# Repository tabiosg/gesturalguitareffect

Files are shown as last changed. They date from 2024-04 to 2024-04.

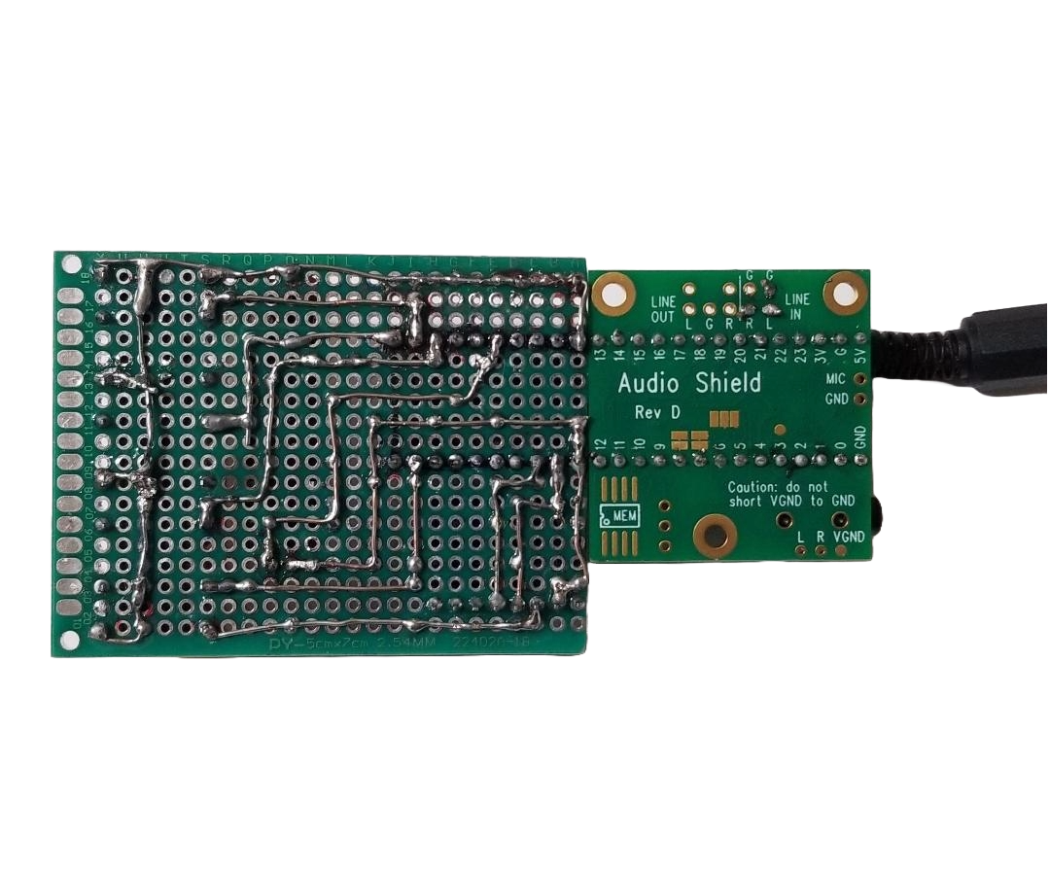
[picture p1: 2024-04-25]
design/protoboard_back.png

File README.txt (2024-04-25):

Gesturally Controlled Guitar Sound Effects Board

This project developed a real-time signal-processing sound effects board tailored for musicians' live performances, utilizing microcontrollers to manipulate input signals for specific outputs.
The current implementation allows for tremolo, wah, and delay effects.

This project was made during the W24 semester for EECS 452.

Zip Content:

design/ contains all designs implemented in project.
    This is primarily focused on the 3D-housing info but also the soldered protoboard.
src/ has the source code.
    src/data_collection has the code which was used to collect data during milestone 1
        This was achieved by dumping debug information over serial and having a Python script
        snoop the line.
    fw/final/gesturalguitareffect has the final firmware code to be flashed on the Teensy.
    sim/ has the code to run the simulation, which is independent of real hardware.
2024-Team-1-final.pdf has the final project report.
2024-Team-1-poster.pdf has the poster used during the demo and expo.
COPYRIGHT.txt contains copyright information, and allows usage of project for educational purposes

Contact Information: 
Eric Cooley - ecooley@umich.edu
Guthrie Tabios - tabiosg@umich.edu
Hypatia Magyar - hypatiam@umich.edu
Leah Kim - leahckim@umich.edu
Nicholas West - nicwest@umich.edu

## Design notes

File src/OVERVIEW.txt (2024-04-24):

All of the code in data_collection/ was only used during milestone 1 to get more data. This is optional.
It worked by taking in the serial debug statements printed by the Teensy and plotting that data afterward.
This serial debug feature will not work perfectly with all the newest code changes to the firmware.

All of the code in src/final/gesturalguitareffect is what is needed to be flashed on the Arduino.
The accelerometer.h and potentiometer.h files are self-explanatory.
The guitareffects.h describes all of our possible effects in an enum.
delay.audiogestural.cpp, tremolo.audiogestural.cpp, and wah.audiogestural.cpp have the specific guitar effect implementations.
audiogestural.cpp and audiogestural.h list the generic functions for the custom AudioStream class.
gesturalguitareffect.ino has the main logic for collecting data in the loop(), used to update parameters.

Al of the code in sim/ is what is needed to run the sim.

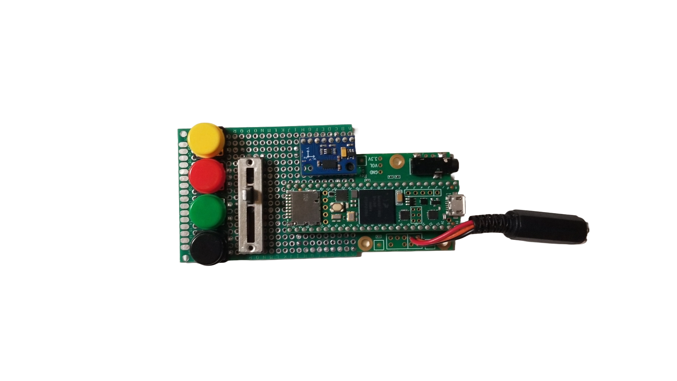
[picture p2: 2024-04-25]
design/protoboard_front.png

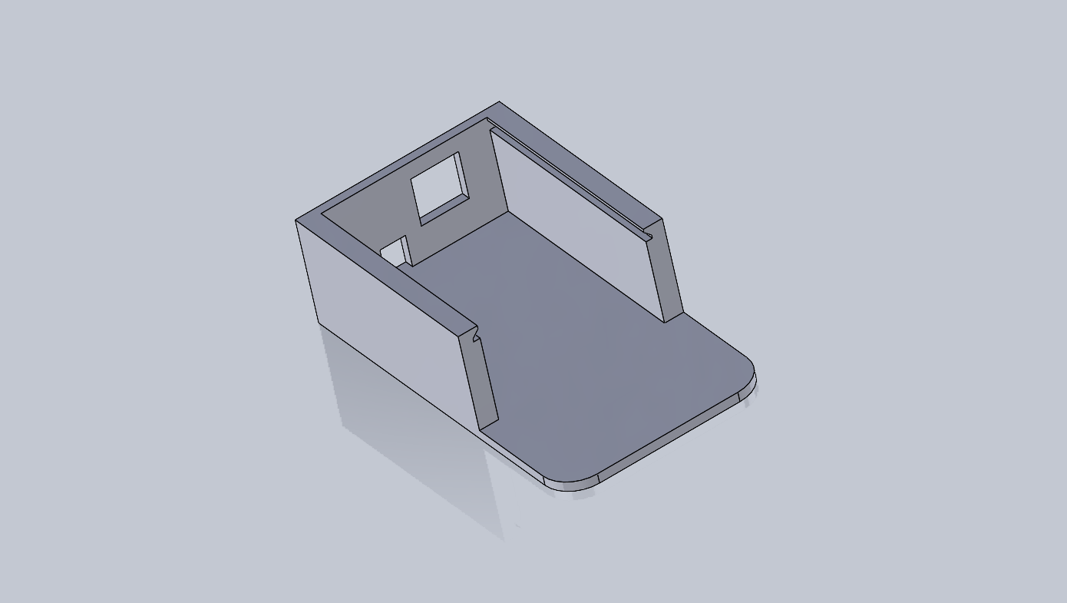
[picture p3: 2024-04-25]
design/box.PNG

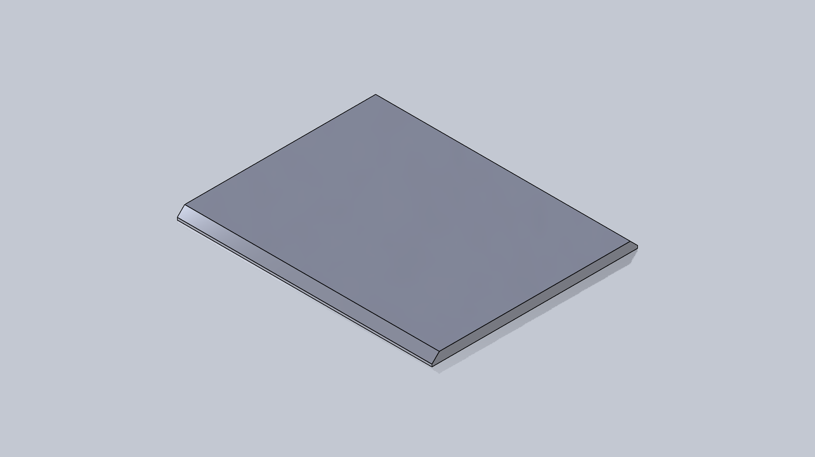
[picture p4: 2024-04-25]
design/lid.PNG

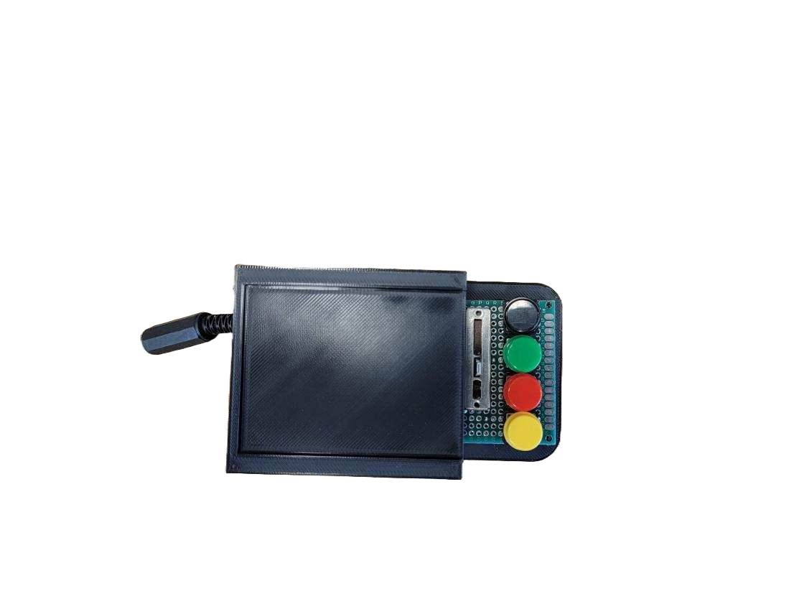
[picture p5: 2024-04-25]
design/final_unit.png

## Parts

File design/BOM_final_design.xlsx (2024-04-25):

Description | Link | Qty | Price
Teensy Audio Shield | From lab | 1 | $16 | Price estimated
Teensy 4.1 | From lab | 1 | $35 | Price estimated
Accelerometer | https://shop.pimoroni.com/en-us/products/lsm303d-6dof-motion-sensor-breakout | 1 | $9.99
Tactile Push Buttons | https://www.amazon.com/Gikfun-12x12x7-3-Tactile-Momentary-Arduino/dp/B01E38OS7K?sp_csd=d2lkZ2V0TmFtZT1zcF9hdGY | 1 | $8.68
Slide Potentiometer | https://www.digikey.com/en/products/detail/bourns-inc/PTA2043-2015CPB103/3781176 | 1 | $1.71
Velcro | https://www.amazon.com/VELCRO-Brand-Fasteners-Industrial-VEL-30703-USA/dp/B09BNPX3XJ | 1 | $8.90
Instrument Cable | Already owned | 1 | $10 | Price estimated
Aux to Instrument Cable Adapter | https://www.amazon.com/TISINO-Female-Headphone-Adapter-Amplifiers/dp/B08KW24ZV9 | 1 | $8.99
Aux Cable | Already owned | 1 | $5 | Price estimted
Total |  |  | $104.27

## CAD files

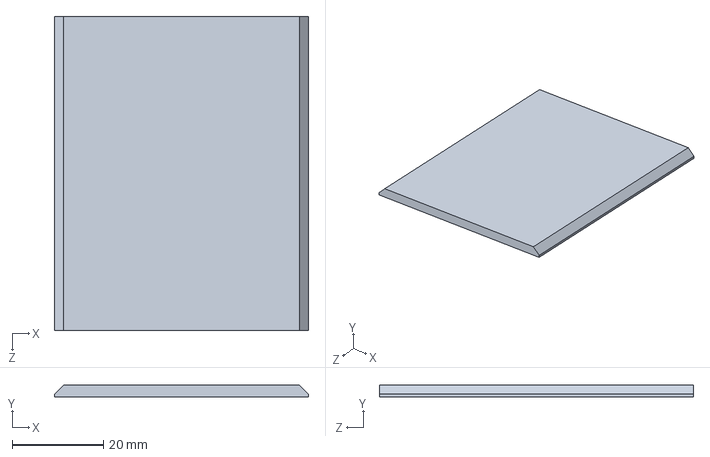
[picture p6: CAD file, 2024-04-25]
design/lid.SLDPRT
55.6 x 2.65 x 68.8 mm

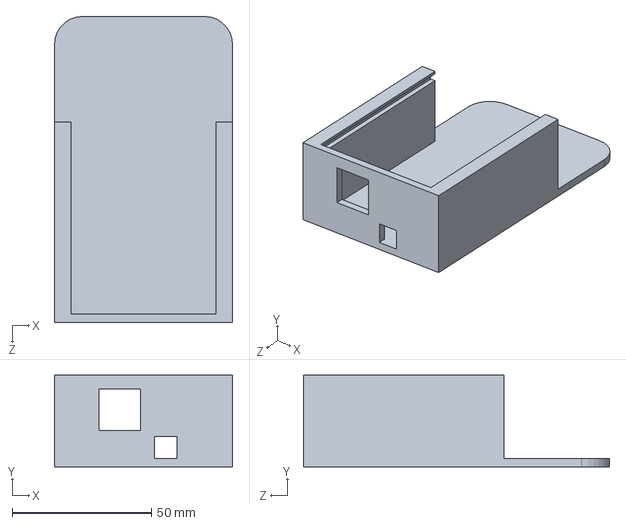
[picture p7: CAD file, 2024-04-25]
design/box.SLDPRT
64.0 x 33.0 x 110.0 mm

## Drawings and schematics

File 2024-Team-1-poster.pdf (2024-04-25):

# Gesturally Controlled Guitar Pedal for Real-Time Effects

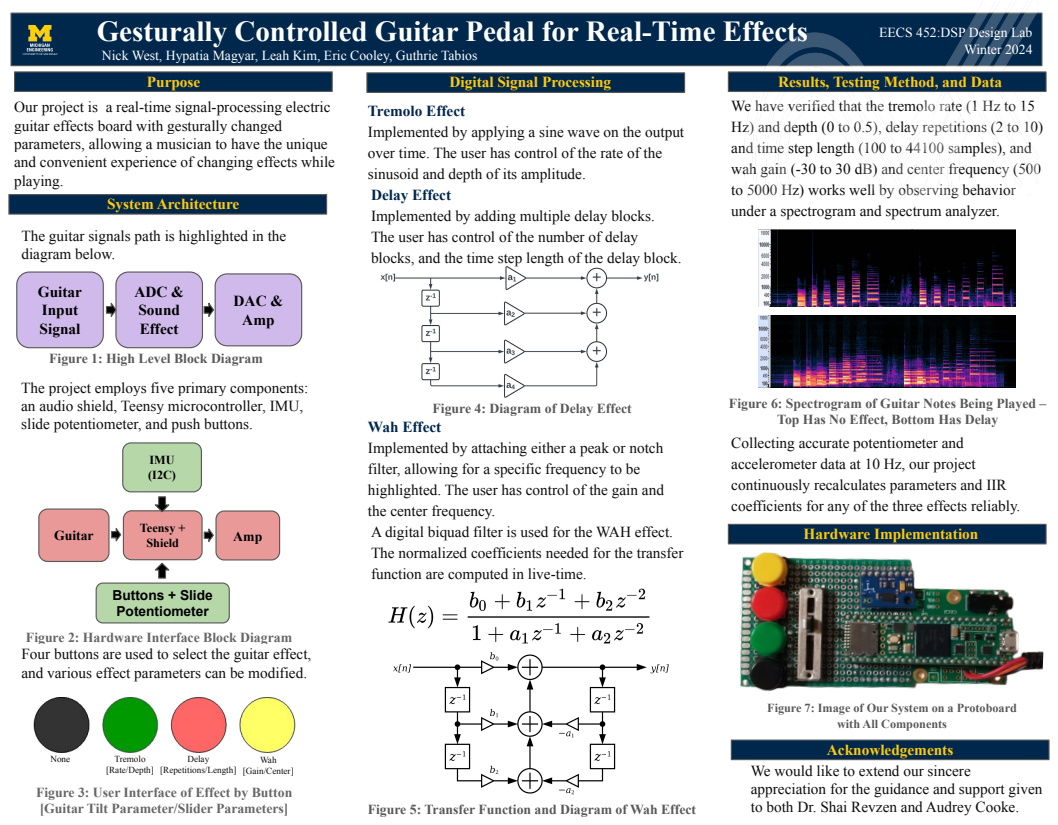
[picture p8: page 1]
Purpose; Digital Signal Processing; Results, Testing Method, and Data; System Architecture; Guitar; Teensy +; Shield; IMU (I2C); Buttons + Slide Potentiometer; Amp; Guitar Input Signal; ADC & Sound Effect; DAC & Amp; Winter 2024; Hardware Implementation; None; Tremolo; [Rate/Depth]; Delay [Repetitions/Length]; Wah [Gain/Center]

EECS 452:DSP Design Lab

Nick West, Hypatia Magyar, Leah Kim, Eric Cooley, Guthrie Tabios

Our project is a real-time signal-processing electric
guitar effects board with gesturally changed
parameters, allowing a musician to have the unique
and convenient experience of changing effects while
playing.

We have verified that the tremolo rate (1 Hz to 15
Hz) and depth (0 to 0.5), delay repetitions (2 to 10)
and time step length (100 to 44100 samples), and
wah gain (-30 to 30 dB) and center frequency (500
to 5000 Hz) works well by observing behavior
under a spectrogram and spectrum analyzer.

Tremolo Effect
Implemented by applying a sine wave on the output
over time. The user has control of the rate of the
sinusoid and depth of its amplitude.
Delay Effect
Implemented by adding multiple delay blocks.
The user has control of the number of delay
blocks, and the time step length of the delay block.

The guitar signals path is highlighted in the
diagram below.

Figure 1: High Level Block Diagram

The project employs five primary components:
an audio shield, Teensy microcontroller, IMU,
slide potentiometer, and push buttons.

Figure 4: Diagram of Delay Effect

Figure 6: Spectrogram of Guitar Notes Being Played –

Wah Effect
Implemented by attaching either a peak or notch
filter, allowing for a specific frequency to be
highlighted. The user has control of the gain and
the center frequency.
A digital biquad filter is used for the WAH effect.
The normalized coefficients needed for the transfer
function are computed in live-time.

Top Has No Effect, Bottom Has Delay

Collecting accurate potentiometer and
accelerometer data at 10 Hz, our project
continuously recalculates parameters and IIR
coefficients for any of the three effects reliably.

Figure 2: Hardware Interface Block Diagram
Four buttons are used to select the guitar effect,
and various effect parameters can be modified.

Figure 7: Image of Our System on a Protoboard

with All Components
Acknowledgements

We would like to extend our sincere
appreciation for the guidance and support given
to both Dr. Shai Revzen and Audrey Cooke.

Figure 3: User Interface of Effect by Button
[Guitar Tilt Parameter/Slider Parameters]

Figure 5: Transfer Function and Diagram of Wah Effect

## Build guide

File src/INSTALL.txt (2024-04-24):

For the code in data_collection/, nothing is neded except for generic python files.

For the code in fw/final/gesturalguitareffect, all that is necessary is the following:
The Arduino application along with the Teensy and Audio Shield library.

For the code in sim/, all that is necessary is the following:
Download mp3 files (preferably, the respective songs), and rename them to be:
["sunflower.mp3", "amidreaming.mp3", "annihilate.mp3", "calling.mp3"].
Other than that, generic python files must be downloaded.

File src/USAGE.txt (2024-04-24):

To run the main project, flash the Teensy with the code in fw/.
The buttons are the following, with the brackets representing the parameters for guitar tilt and slider:
- Black is None
- Green is Tremolo [Rate/Depth]
- Red is Delay [Repetitions/Length]
- Yellow is Wah [Gain/Center]

When running the sim, the GUI itself is self-explanatory, allowing one to switch between different songs and
change the effects' parameters.

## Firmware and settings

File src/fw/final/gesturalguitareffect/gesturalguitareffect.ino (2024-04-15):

#include <Arduino.h>
#include <AudioStream.h>

#define SAMPLE_CYCLES 128

#include "accelerometer.h"
#include "guitareffects.h"
#include "audiogestural.h"
#include "potentiometer.h"

#include <Wire.h>

#include <Audio.h>
#include <SPI.h>

// Define the audio connections
AudioInputI2S            input;        // Input from audio codec
AudioOutputI2S           output;       // Output to audio codec
AudioControlSGTL5000     codec;        // Audio codec control

// Wire: SDA is 18, SCL is 19  - https://www.pjrc.com/teensy/td_libs_Wire.html
// Wire2: SDA is 25, SCL is 24  - https://www.pjrc.com/teensy/td_libs_Wire.html

#define NONE_PIN 34 
#define TREMOLO_PIN 33
#define DELAY_PIN 35
#define WAH_PIN 31

AudioEffectGesture gAudioEffectGesture;
Accelerometer gAccel;
Potentiometer gPotentiometer;

// Define audio connections using AudioConnection
AudioConnection          patchCord1(input, 0, gAudioEffectGesture, 0);

AudioConnection          patchCord3(gAudioEffectGesture, 0, output, 0);
AudioConnection          patchCord4(gAudioEffectGesture, 0, output, 1);

void setup() {
  Serial.begin(9600); // Initialize Serial communication

   // Initialize the audio shield and codec
  AudioMemory(12);
  codec.enable();
  codec.inputSelect(AUDIO_INPUT_LINEIN);  // Set input source (e.g., LINE-IN or MIC)
  codec.volume(0.6);                      // Set volume level

  delay(1000); // Delay for stability

  pinMode(NONE_PIN, INPUT_PULLUP);
  pinMode(TREMOLO_PIN, INPUT_PULLUP);
  pinMode(DELAY_PIN, INPUT_PULLUP);
  pinMode(WAH_PIN, INPUT_PULLUP);

  attachInterrupt(digitalPinToInterrupt(NONE_PIN), doNoneEffect, RISING);
  attachInterrupt(digitalPinToInterrupt(TREMOLO_PIN), doTremoloEffect, RISING);
  attachInterrupt(digitalPinToInterrupt(DELAY_PIN), doDelayEffect, RISING);
  attachInterrupt(digitalPinToInterrupt(WAH_PIN), doWahEffect, RISING);

  gAccel.setup();
}

void loop() {
  #ifdef DEBUG
  gAudioEffectGesture.printEffect();
  #endif
  __disable_irq();
  float potentData = gPotentiometer.getConvertedData();
  gAudioEffectGesture.updatePotentiometer(potentData); 
  float accelData = gAccel.getZDegrees();
  gAudioEffectGesture.updateAccelerometer(-accelData);
  gAudioEffectGesture.applyPeakingCoefficients();
  __enable_irq();
  delay(33); // Delay before next iteration
}

void doNoneEffect() {
  gAudioEffectGesture.changeEffect(GuitarEffect::None);
}

void doTremoloEffect() {
  gAudioEffectGesture.changeEffect(GuitarEffect::Tremolo);
}

void doDelayEffect() {
  gAudioEffectGesture.changeEffect(GuitarEffect::Delay);
}

void doWahEffect() {
  gAudioEffectGesture.changeEffect(GuitarEffect::Wah);
}

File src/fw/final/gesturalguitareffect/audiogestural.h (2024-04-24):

#include <Audio.h>
#include "guitareffects.h"

#define DELAY_LENGTH 44100

#define MAX_NUMBER_DELAY_REPEATS 10  // Needs to be 2 or greater
#define MIN_NUMER_DELAY_REPEATS 2
#define MAX_DELAY_STEP_SIZE (DELAY_LENGTH / (mCurrentNumberDelayRepeats - 1))
#define MIN_DELAY_STEP_SIZE 4000

#define MIN_CENTER_FREQUENCY 100
#define MAX_CENTER_FREQUENCY 7000
#define CENTER_FREQUENCY_RESOLUTION 10
#define GAIN_RESOLUTION 10
#define MIN_GAIN -10
#define MAX_GAIN 20

#define REPEATS_RESOLUTION 5
#define STEP_SIZE_RESOLUTION 5

#define MIN_RATE 1
#define MAX_RATE 15
#define RATE_RESOLUTION 10
#define DEPTH_RESOLUTION 10

#define ACCEL_MIN_DEG_FOR_INPUT -20
#define ACCEL_MAX_DEG_FOR_INPUT 30 // Degrees since we noticed that anything above 50 degrees is not too accurate. -- but 50 degrees is a lot to move
#define ACCEL_DEG_THRESHOLDING 1

#define ACCEL_CALLS_TO_WAIT_BEFORE_UPDATING_AGAIN 3

// #define DEBUG

class AudioEffectGesture : public AudioStream {
public:

  AudioEffectGesture();

  void changeEffect(GuitarEffect effect);

  virtual void update(void);

  void updatePotentiometer(float value);

  void updateAccelerometer(float value);

  void applyPeakingCoefficients();

  GuitarEffect getEffect() {
    return mCurrentEffect;
  }

  void printEffect() {
    #ifdef DEBUG
    switch (mCurrentEffect) {
        case GuitarEffect::None:
            Serial.println("$EFFECT, None");
            break;
        case GuitarEffect::Tremolo:
            Serial.println("$EFFECT, Tremolo");
            break;
        case GuitarEffect::Delay:
            Serial.println("$EFFECT, Delay");
            break;
        case GuitarEffect::Wah:
            Serial.println("$EFFECT, Wah");
            break;
        default:
            Serial.println("Unknown effect");
    }
    #endif
  }

private:
  void applyDelay(audio_block_t *block);

  void updateTremolo(audio_block_t *block, int startingIndex);

  void updateDelayBuffer(audio_block_t *block);

  void peakingCoefficients(float G, float fc, float Q, float fs);

  void applyBiquad(float32_t *input, float32_t *output, uint32_t blockSize);

  int calculateRepeats(float input);

  int calculateStepSize(float input);

  float calculateDepth(float input);

  float calculateRate(float input);

  int calculateGain(float input);

  int calculateCenterFrequency(float input);

  float convertAccelValueToInput(float value);

  GuitarEffect mCurrentEffect;
  audio_block_t *inputQueueArray[1];
  int16_t mDelayBuffer[DELAY_LENGTH];
  uint32_t mWriteIndex;
  int mCurrentNumberDelayRepeats;
  int mCurrentDelayStepSize;
  float mDelayRatios[MAX_NUMBER_DELAY_REPEATS];
  float mDepth; 
  float mRate;

  float mCurrentCenterFrequency;
  float mCurrentGain; 

  float32_t mb0, mb1, mb2, ma1, ma2;
};

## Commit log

2024-03-11 Add initial accelerometer code
2024-03-13 Test accelerometer
2024-03-16 Add potentiometer and accelerometer features
2024-03-16 Add support for changing delay time on accelerometer:
2024-03-20 Implement delay wanted by Nick and fix tremolo to not clip
    [audiogestural.cpp, audiogestural.h]
2024-03-20 Add changes to get rid of noise
    [audiogestural.cpp, audiogestural.h, gesturalguitareffect.ino]
2024-04-06 Add example WAH filter code - but instead use LP as a base
2024-04-06 Add preliminary biquad IIR and peaking Filter, but unsure if it actually works
2024-04-12 Refactor code - but now it introduces a bit of noise on delay and tremolo
    [audiogestural.cpp, audiogestural.h]
2024-04-15 Add more song options to the GUI and fix logic when switching
2024-04-25 Add requirements for official report
    [BOM_final_design.xlsx, box.SLDPRT, lid.SLDPRT]
